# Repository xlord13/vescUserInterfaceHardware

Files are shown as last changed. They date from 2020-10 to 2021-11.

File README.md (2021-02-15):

# User interface board for VESC controller on e-twow scooter

This user interface board is based on an stm32F4 microcontroler.
The hardware design has been optimized for e-twow scooters, but can be adapted to any electric engine.
Is has been made with KiCad, which is a cross platform and open source electronics design automation suite.

This board communicates with a VESC controller by a UART interface.
It has 4 buttons and a color OLED 128x128 display (SSD1351) for user interaction.
Additionnaly, it includes 6 leds and a photo resistor for automatic lighting when ambient lighting is too low.

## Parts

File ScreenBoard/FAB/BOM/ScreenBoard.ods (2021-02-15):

Component Count: | 23
Ref | Qnty | Value | Cmp name | Footprint | Description | Vendor | Ref
C1, C4, C7, C10, | 4 | 4.7µF | C_Small | Capacitor_SMD:C_0603_1608Metric_Pad1.05x0.95mm_HandSolder | Unpolarized capacitor, small symbol | Mouser
C2, C9, | 2 | 100nF | C_Small | Capacitor_SMD:C_0603_1608Metric_Pad1.05x0.95mm_HandSolder | Unpolarized capacitor, small symbol | Farnell
C3, C11, | 2 | 10µF | C_Small | Capacitor_SMD:C_1206_3216Metric_Pad1.42x1.75mm_HandSolder | Unpolarized capacitor, small symbol | Mouser
C5, C8, | 2 | 1µF | C_Small | Capacitor_SMD:C_0805_2012Metric_Pad1.15x1.40mm_HandSolder | Unpolarized capacitor, small symbol | Mouser
C6, | 1 | 120pF | C_Small | Capacitor_SMD:C_0603_1608Metric_Pad1.05x0.95mm_HandSolder | Unpolarized capacitor, small symbol | Mouser
D1, D2, | 2 | 1N4148WT | 1N4148WT | Diode_SMD:D_SOD-523 | 75V 0.15A Fast switching Diode, SOD-523 | Mouser
D3, | 1 | MBRS130LT3G | D_Schottky_ALT | Diode_SMD:D_SMB_Handsoldering | Schottky diode, filled shape | Mouser
IC1, | 1 | FAN5331SX | FAN5331SX | SOT95P280X145-5N | ON Semiconductor FAN5331SX, LED Driver, 3.3 V, 5 V, 5-Pin SOT-23 | Mouser
J1, | 1 | Micro_SD_Card | Micro_SD_Card | SamacSys_Parts:693072010801 | Micro SD Card Socket | Mouser
J2, | 1 | Conn_02x05_Male | Conn_02x05_Odd_Even | Connector_PinHeader_2.00mm:PinHeader_2x05_P2.00mm_Vertical_SMD | Generic connector, double row, 02x05, odd/even pin numbering scheme (row 1 odd numbers, row 2 even numbers), script generated (kicad-library-utils/schlib/autogen/connector/) | Mouser
K1, | 1 | OLED connector | K_0051-DVB_K-DK3_GUI-PI-rescue | SamacSys_Parts:52435-3071 |  | Mouser
L1, | 1 | 10µH | L_Small | Inductor_SMD:L_Coilcraft_LPS5030 | Inductor, small symbol | Mouser
R1, | 1 | 56 Ohm | R_Small | Resistor_SMD:R_0603_1608Metric_Pad1.05x0.95mm_HandSolder | Resistor, small symbol | Mouser
R2, | 1 | 10k | R_Small | Resistor_SMD:R_0603_1608Metric_Pad1.05x0.95mm_HandSolder | Resistor, small symbol | Farnell
R3, | 1 | 100k | R_Small | Resistor_SMD:R_0603_1608Metric_Pad1.05x0.95mm_HandSolder | Resistor, small symbol | Mouser
R4, | 1 | 600k (604k) | R_Small | Resistor_SMD:R_0603_1608Metric_Pad1.05x0.95mm_HandSolder | Resistor, small symbol | Mouser

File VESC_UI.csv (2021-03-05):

Ref | Qnty | Value | Cmp name | Footprint | Description | Vendor
C1, | 1 | 10n | C_Small | Capacitor_SMD:C_0603_1608Metric_Pad1.05x0.95mm_HandSolder | Unpolarized capacitor, small symbol
C2, | 1 | 10µF | C | Capacitor_SMD:C_0805_2012Metric_Pad1.15x1.40mm_HandSolder | Unpolarized capacitor
C6, C9, C10, C12, C15, C19, C20, C21, C23, C24, | 10 | 100n | C_Small | Capacitor_SMD:C_0603_1608Metric_Pad1.05x0.95mm_HandSolder | Unpolarized capacitor, small symbol
C18, | 1 | 4.7u | C_Small | Capacitor_SMD:C_0603_1608Metric_Pad1.05x0.95mm_HandSolder | Unpolarized capacitor, small symbol
C22, | 1 | SUpercap 330mF | Battery_Cell | SamacSys_Parts:DSK3R3H334THL | Single-cell battery
D1, D2, D3, D4, D5, D6, | 6 | LED 5mm - White | LED_Small_ALT | LED_THT:LED_D5.0mm_Horizontal_O1.27mm_Z3.0mm_Clear | Light emitting diode, small symbol, filled shape
D10, | 1 | Schottky CD0603-B0240R | D_Schottky_Small_ALT | Diode_SMD:D_0603_1608Metric_Pad1.05x0.95mm_HandSolder | Schottky diode, small symbol, filled shape
J1, J2, | 2 | Hall_SS441R | Conn_01x03_Female | Package_TO_SOT_THT:TO-92Flat | Generic connector, single row, 01x03, script generated (kicad-library-utils/schlib/autogen/connector/)
J3, | 1 | Conn_01x07_Male | Conn_01x07_Male | Connector_JST:JST_PH_B7B-PH-K_1x07_P2.00mm_Vertical | Generic connector, single row, 01x07, script generated (kicad-library-utils/schlib/autogen/connector/)
J4, | 1 | Conn_02x05_Female | Conn_02x05_Odd_Even | Connector_PinSocket_2.00mm:PinSocket_2x05_P2.00mm_Vertical | Generic connector, double row, 02x05, odd/even pin numbering scheme (row 1 odd numbers, row 2 even numbers), script generated (kicad-library-utils/schlib/autogen/connector/)
J5, | 1 | Conn_01x05_Male | Conn_01x05_Male | Connector_JST:JST_PH_B5B-PH-K_1x05_P2.00mm_Vertical | Generic connector, single row, 01x05, script generated (kicad-library-utils/schlib/autogen/connector/)
J6, | 1 | Conn_01x04_Male | Conn_01x04_Male | Connector_JST:JST_PH_B4B-PH-K_1x04_P2.00mm_Vertical | Generic connector, single row, 01x04, script generated (kicad-library-utils/schlib/autogen/connector/)
J8, J9, | 2 | Conn_01x02_Male | Conn_01x02_Male | Connector_JST:JST_PH_B2B-PH-K_1x02_P2.00mm_Vertical | Generic connector, single row, 01x02, script generated (kicad-library-utils/schlib/autogen/connector/)
JP1, JP2, | 2 | Jumper_NC_Small | Jumper_NC_Small | Jumper:SolderJumper-2_P1.3mm_Open_TrianglePad1.0x1.5mm | Jumper, normally closed, small symbol
L2, | 1 | MMZ1608B121CTDH5 | L_Core_Iron_Small | Inductor_SMD:L_0603_1608Metric_Pad1.05x0.95mm_HandSolder | Inductor with iron core, small symbol
Q1, Q2, | 2 | Mosfet IRLML2060TRPBF | IRLML2060 | Package_TO_SOT_SMD:SOT-23 | 1.2A Id, 60V Vds, N-Channel MOSFET, 480mOhm Rds, SOT-23
R1, R4, R6, R10, R11, R15, | 6 | 62 | R_Small | Resistor_SMD:R_0603_1608Metric_Pad1.05x0.95mm_HandSolder | Resistor, small symbol
R2, | 1 | 100k | R_Small | Resistor_SMD:R_0603_1608Metric_Pad1.05x0.95mm_HandSolder | Resistor, small symbol
R3, R5, R7, R9, R12, | 5 | 100 | R_Small | Resistor_SMD:R_0603_1608Metric_Pad1.05x0.95mm_HandSolder | Resistor, small symbol
R8, | 1 | 1M | R_Small | Resistor_SMD:R_0603_1608Metric_Pad1.05x0.95mm_HandSolder | Resistor, small symbol
R13, | 1 | NSL-19M51 | R_PHOTO | OptoDevice:R_LDR_4.9x4.2mm_P2.54mm_Vertical | Photoresistor
R14, R21, R22, | 3 | 10k | R_Small | Resistor_SMD:R_0603_1608Metric_Pad1.05x0.95mm_HandSolder | Resistor, small symbol
R17, R18, | 2 | 0 | R_Small | Resistor_SMD:R_0603_1608Metric_Pad1.05x0.95mm_HandSolder | Resistor, small symbol
SW1, SW2, SW3, SW4, | 4 | Vertical push button | SW_Push | SamacSys_Parts:Vertical_push_button | Push button switch, generic, two pins
SW5, | 1 | Push button | SW_Push | Button_Switch_SMD:SW_SPST_B3U-1000P-B | Push button switch, generic, two pins
U2, | 1 | STM32F401CEU6 | STM32F401CEUx | Package_DFN_QFN:QFN-48-1EP_7x7mm_P0.5mm_EP5.6x5.6mm | ARM Cortex-M4 MCU, 512KB flash, 96KB RAM, 84MHz, 1.7-3.6V, 36 GPIO, UFQFPN-48
U3, | 1 | M95M04-DR | M95256-WMN6P | Package_SO:SOIC-8_3.9x4.9mm_P1.27mm | SPI EEPROM, 256Kb (32K x 8), No Identification Page, 2.5 to 5.5V, SO8

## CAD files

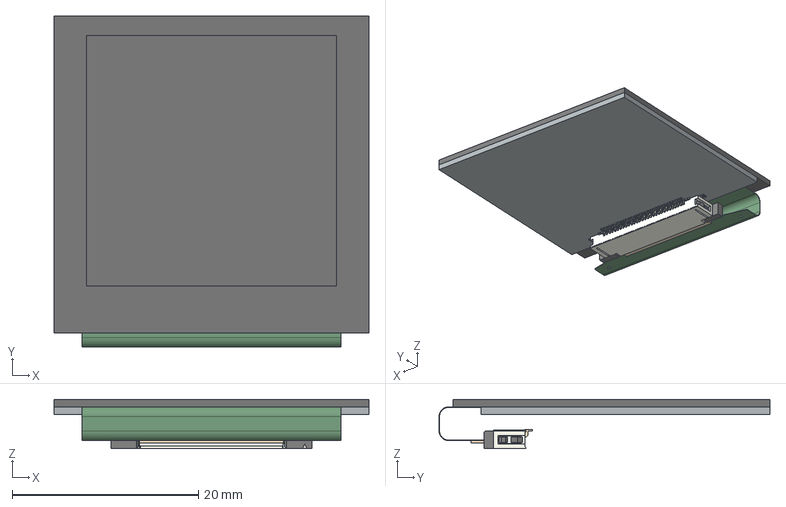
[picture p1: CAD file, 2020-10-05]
3D/SSD1351/SSD1351_Connector_v3_cp.step
33.8 x 35.5 x 5.27 mm

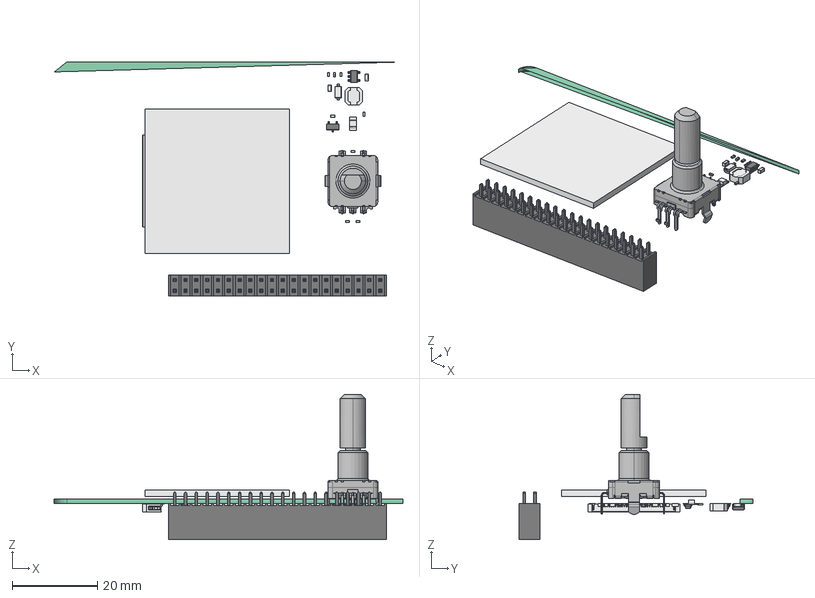
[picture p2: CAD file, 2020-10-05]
VESC_UI.FCStd
82.0 x 55.0 x 34.1 mm
Pcb_cf18
SW1_EC11E-05SW_5F084975
C8_C_0805_5CB976D5
R1_R_0402_5CB88870
D4_LED_3216-RV-red_5CBB4279
R8_R_0402_5F09672A
L1_Coilcraft-LPZ4018_5CB8885F
C1_C_0603_5CB8871C
C9_C_0603_5CB977C8
C10_C_0603_5CB976A5
D3_D_SOD-523_5CB97622
C6_C_0603_5CB97738
Q1_SOT_23_5CC6B4F7
K1_52435-3071_5CB9753E
K1__24353071_cp_sp_5CB9753E[2]
R3_R_0402_5CB975EB
C13_C_0402_5D56A2AD
U1_SOT_23_5_5CB888B8
C5_C_1206_5CB97768
C4_C_0603_5CB8874F
R10_R_0402_5CD18970
R9_R_0402_5CC6B508
R2_R_0402_5CB88881
R6_R_0402_5D5FDE48
C3_C_0603_5CB97798
C14_C_0402_5D56A2BE
D2_D_SOD-523_5CB97667
C7_C_0805_5CB97708
C2_C_0402_5CB8872D
R11_R_0402_5D56A2E0
R4_R_0402_5CBA7511
D1_D_SOD-123_5CB887CE
C15_C_0402_5D56A2CF
K6__SSQ-120-01-G-D_terminal_sp_5CADED16

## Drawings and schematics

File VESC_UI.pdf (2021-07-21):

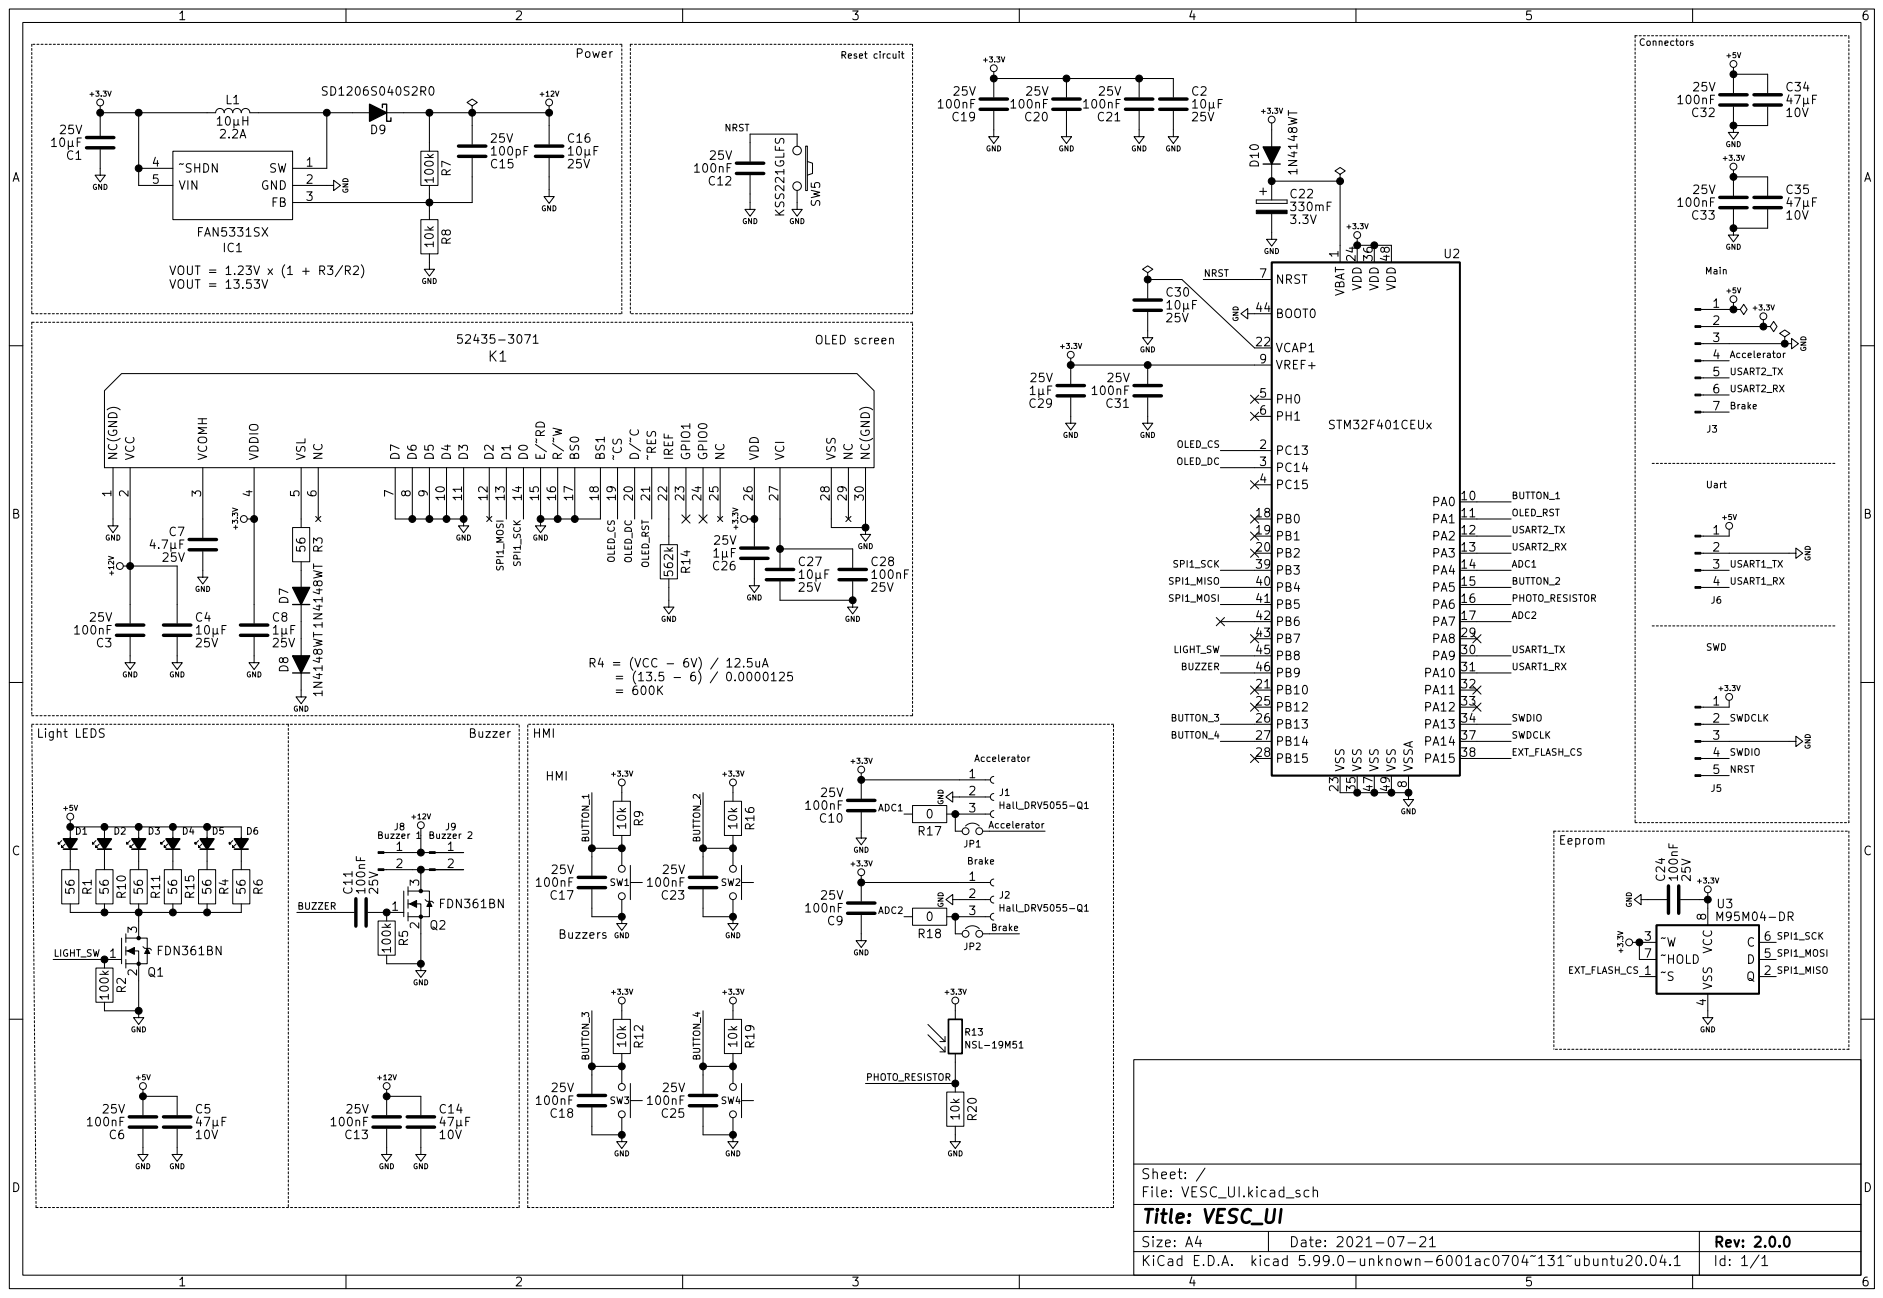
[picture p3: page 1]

1 PA0 10 PA1 11 PA2 12 PA3 13 PA4 14 PA5 15 PA6 16 PA7 17 PB0 18 PB1 19 PC13 2 PB2 20 PB10 21 VCAP1 22 VSS 23 VDD 24 PB12 25 PB13 26 PB14 27 PB15 28 PA8 29 PC14 3 PA9 30 PA10 31 PA11 32 PA12 33 PA13 34 VSS 35 VDD 36 PA14 37 PA15 38 PB3 39 PC15 4 PB4 40 PB5 41 PB6 42 PB7 43 BOOT0 44 PB8 45 PB9 46 VSS 47 VDD 48 VSS 49 PH0 5 PH1 6 NRST 7 VSSA

2 D/~C 20 ~RES 21 IREF 22 GPIO1 23 GPIO0 24 NC 25 VDD 26 VCI 27 VSS 28 NC 29 VCOMH

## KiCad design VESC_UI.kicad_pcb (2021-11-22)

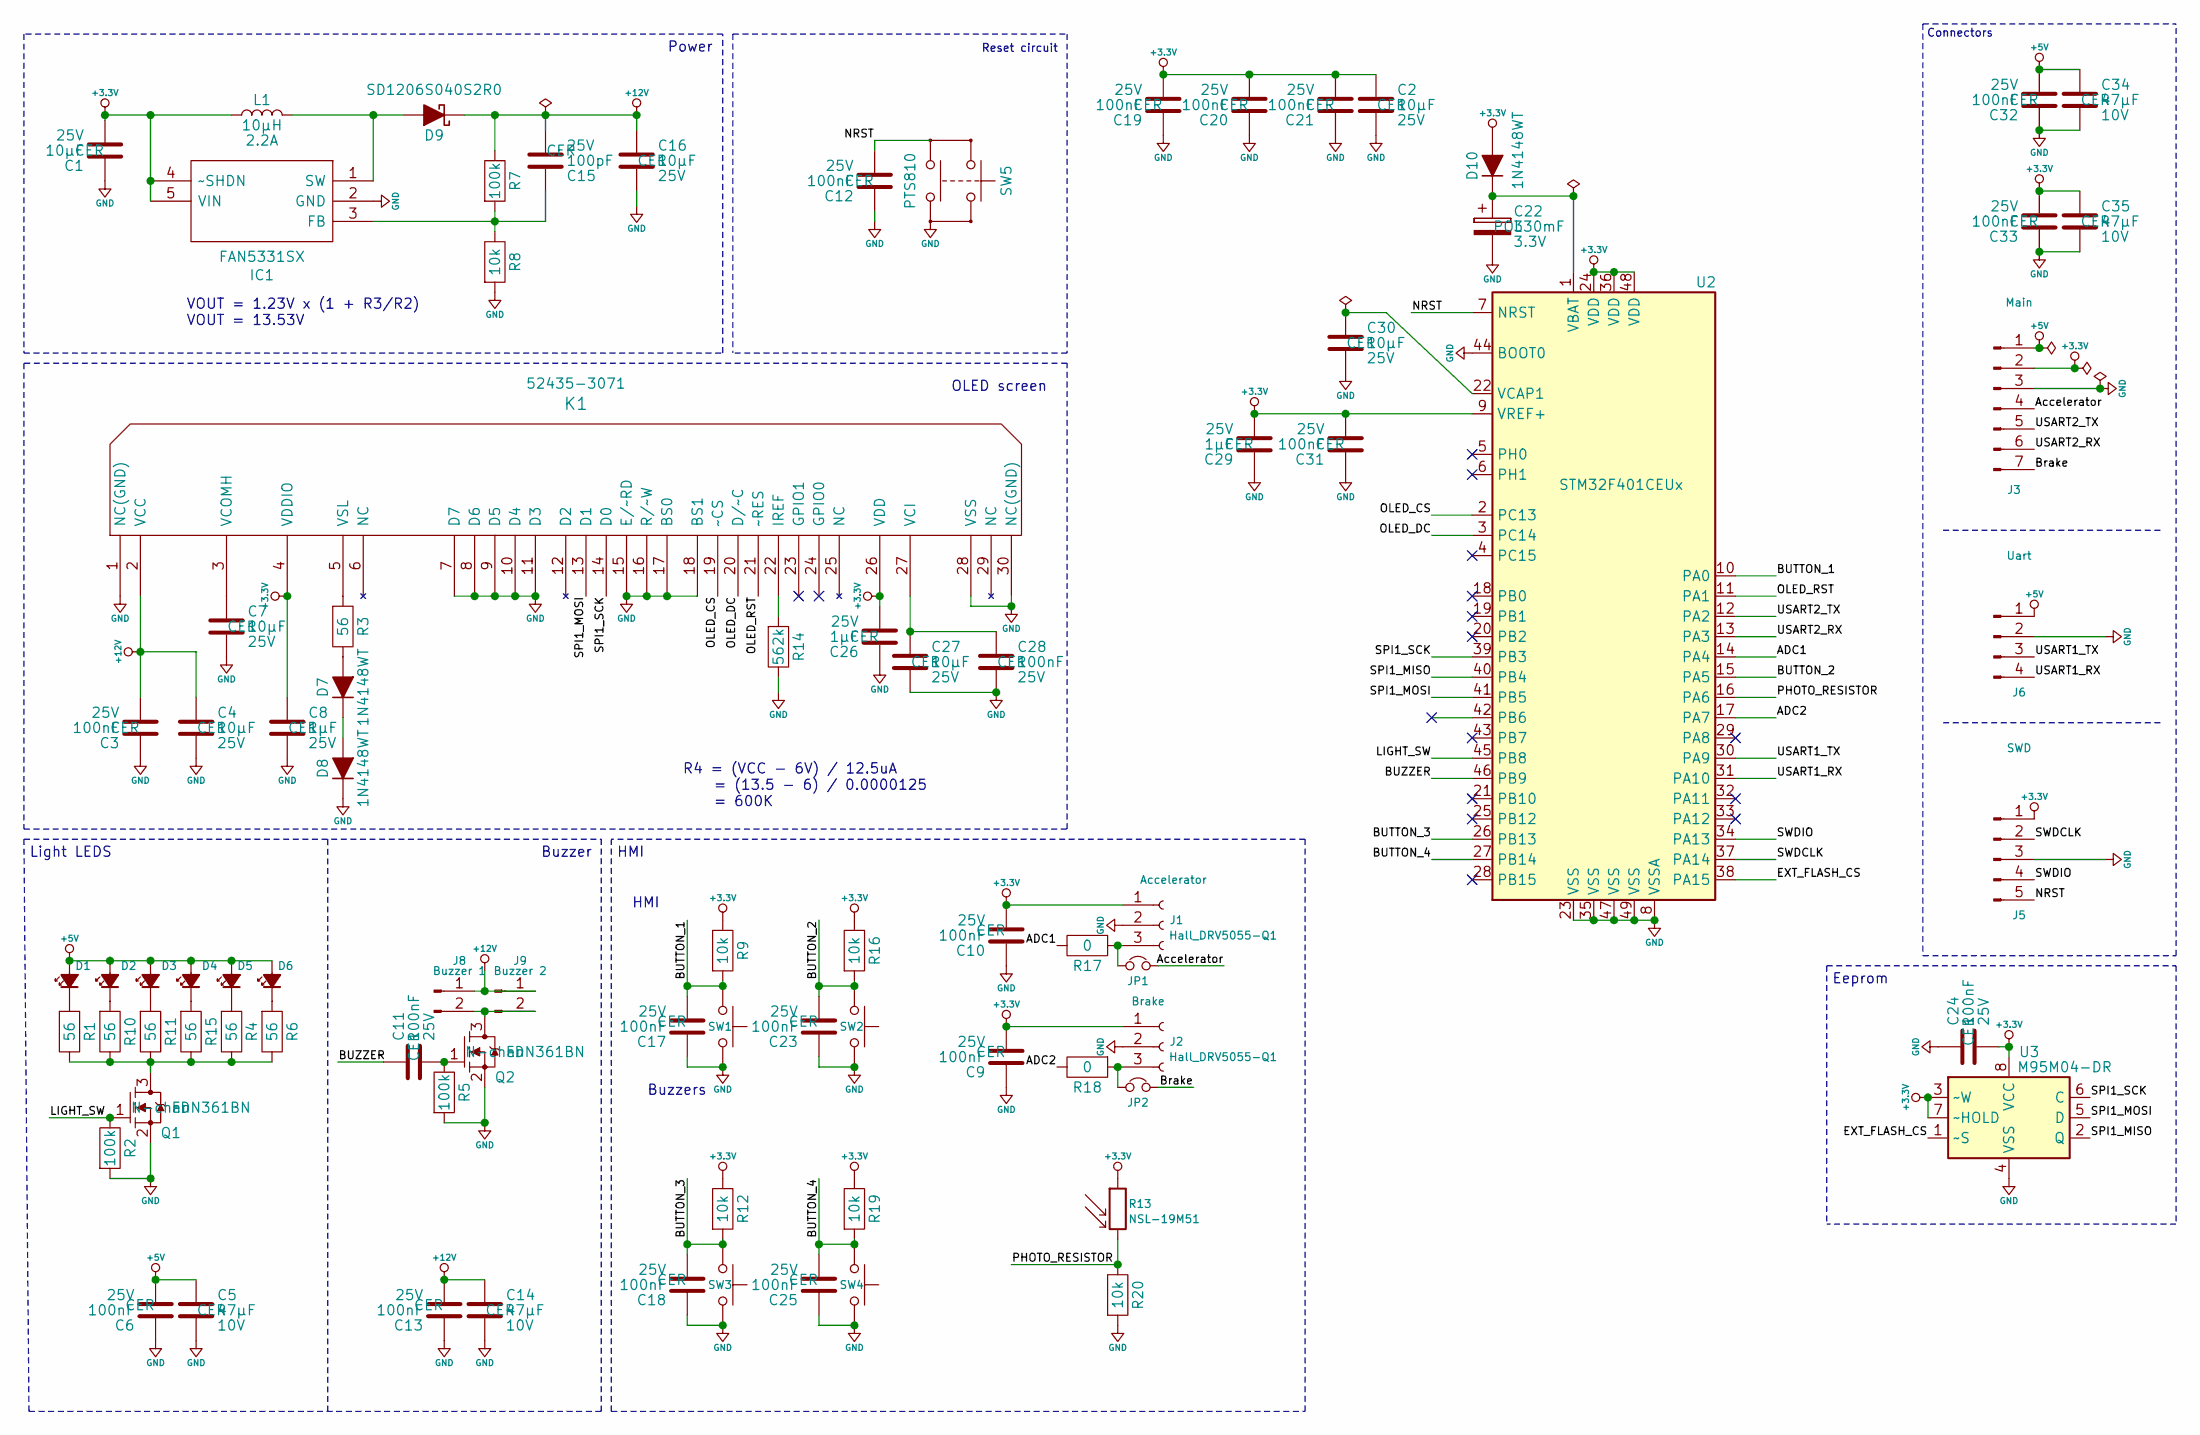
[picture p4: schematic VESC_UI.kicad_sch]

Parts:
C1, C2, C4, C7, C16, C27, C30: C_0003; C_0603
C3, C6, C9, C10, C11, C12, C13, C17, C18, C19, C20, C21, C23, C24, C25, C28, C31, C32, C33: C_0002; C_0402
C5, C14, C34, C35: C_0040; C_1210
C8, C26, C29: C_0037; C_0603
C15: C_0051; C_0402
C22: C_0046; CP_ELNA-DSK621
D1, D2, D3, D4, D5, D6: LED 5mm - White; LED_D5.0mm_Horizontal_O1.27mm_Z3.0mm_Clear
D7, D8, D10: D_0022; D_SOD-523-F
D9: D_0016; D_SOD-123
IC1: FAN5331SX; SOT95P280X145-5N; Mouser Part Number 512-FAN5331SX
J1, J2: Hall_DRV5055-Q1; TO-92Flat
J3: Conn_01x07_Male; JST_PH_B7B-PH-K_1x07_P2.00mm_Vertical
J5: Conn_01x05_Male; JST_PH_B5B-PH-K_1x05_P2.00mm_Vertical
J6: Conn_01x04_Male; JST_PH_B4B-PH-K_1x04_P2.00mm_Vertical
J8, J9: Conn_01x02_Male; JST_PH_B2B-PH-K_1x02_P2.00mm_Vertical
JP1, JP2: Jumper_NC_Small; SolderJumper-2_P1.3mm_Open_TrianglePad1.0x1.5mm
K1: K_0051-OBSOLETE; OLED128x128-1P5
L1: L_0006; L_4012-Wurth
Q1, Q2: Q_0020; SOT_23
R1, R4, R6, R10, R11, R15: R_0110; R_0603
R2, R5, R7: R_0034; R_0402
R3: R_0110; R_0402
R8, R9, R12, R16, R19, R20: R_0020; R_0402
R13: NSL-19M51; R_LDR_4.9x4.2mm_P2.54mm_Vertical
R14: R_0019; R_0402
R17, R18: R_0001; R_0402
SW1, SW2, SW3, SW4: Vertical push button; Vertical_push_button
SW5: SW_0003; PTS810
U2: STM32F401CEUx; QFN-48-1EP_7x7mm_P0.5mm_EP5.6x5.6mm
U3: M95M04-DR; SOIC-8_3.9x4.9mm_P1.27mm

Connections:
+3.3V: C1.2, C2.1, C8.1, C9.2, C10.2, C19.2, C20.2, C21.2, C24.2, C26.2, C29.2, C31.2, C33.2, C35.1, D10.2 (A), IC1.4 (~SHDN), IC1.5 (VIN), J1.1, J2.1, J3.2, J5.1, K1.4 (VDDIO), K1.26 (VDD), L1.2, R9.2, R12.2, R13.1, R16.2, R19.2, U2.9 (VREF+), U2.24 (VDD), U2.36 (VDD), U2.48 (VDD), U3.3 (~W), U3.7 (~HOLD), U3.8 (VCC)
+5V: C5.1, C6.2, C32.2, C34.1, D1.2 (A), D2.2 (A), D3.2 (A), D4.2 (A), D5.2 (A), D6.2 (A), J3.1, J6.1
+12V: C3.2, C4.1, C13.2, C14.1, C15.2, C16.1, D9.1 (K), J8.1, J9.1, K1.2 (VCC), R7.2
/ADC1: R17.2, U2.14 (PA4)
/ADC2: R18.2, U2.17 (PA7)
/Accelerator: J3.4, JP1.2
/BUTTON_1: C17.2, R9.1, SW1.1, U2.10 (PA0)
/BUTTON_2: C23.2, R16.1, SW2.1, U2.15 (PA5)
/BUTTON_3: C18.2, R12.1, SW3.1, U2.26 (PB13)
/BUTTON_4: C25.2, R19.1, SW4.1, U2.27 (PB14)
/BUZZER: C11.1, U2.46 (PB9)
/Brake: J3.7, JP2.2
/EXT_FLASH_CS: U2.38 (PA15), U3.1 (~S)
/LIGHT_SW: Q1.1 (G), R2.2, U2.45 (PB8)
/NRST: C12.2, J5.5, SW5.2, U2.7 (NRST)
/OLED_CS: K1.19 (~CS), U2.2 (PC13)
/OLED_DC: K1.20 (D/~C), U2.3 (PC14)
/OLED_RST: K1.21 (~RES), U2.11 (PA1)
/PHOTO_RESISTOR: R13.2, R20.2, U2.16 (PA6)
/SPI1_MISO: U2.40 (PB4), U3.2 (Q)
/SPI1_MOSI: K1.13 (D1), U2.41 (PB5), U3.5 (D)
/SPI1_SCK: K1.14 (D0), U2.39 (PB3), U3.6 (C)
/SWDCLK: J5.2, U2.37 (PA14)
/SWDIO: J5.4, U2.34 (PA13)
/USART1_RX: J6.4, U2.31 (PA10)
/USART1_TX: J6.3, U2.30 (PA9)
/USART2_RX: J3.6, U2.13 (PA3)
/USART2_TX: J3.5, U2.12 (PA2)
GND: C1.1, C2.2, C3.1, C4.2, C5.2, C6.1, C7.2, C8.2, C9.1, C10.1, C12.1, C13.1, C14.2, C16.2, C17.1, C18.1, C19.1, C20.1, C21.1, C22.2, C23.1, C24.1, C25.1, C26.1, C27.2, C28.2, C29.1, C30.2, C31.1, C32.1, C33.1, C34.2, C35.2, D8.1 (K), IC1.2 (GND), J1.2, J2.2, J3.3, J5.3, J6.2, K1.1 (NC(GND)), K1.7 (D7), K1.8 (D6), K1.9 (D5), K1.10 (D4), K1.11 (D3), K1.15 (E/~RD), K1.16 (R/~W), K1.17 (BS0), K1.18 (BS1), K1.28 (VSS), K1.30 (NC(GND)), Q1.2 (S), Q2.2 (S), R2.1, R5.1, R8.1, R14.2, R20.1, SW1.2, SW2.2, SW3.2, SW4.2, SW5.3, U2.8 (VSSA), U2.23 (VSS), U2.35 (VSS), U2.44 (BOOT0), U2.47 (VSS), U2.49 (VSS), U3.4 (VSS)
unnamed: C7.1, K1.3 (VCOMH)
unnamed: C11.2, Q2.1 (G), R5.2
unnamed: C15.1, IC1.3 (FB), R7.1, R8.2
unnamed: C22.1, D10.1 (K), U2.1 (VBAT)
unnamed: C27.1, C28.1, K1.27 (VCI)
unnamed: C30.1, U2.22 (VCAP1)
unnamed: D1.1 (K), R1.1
unnamed: D2.1 (K), R10.1
unnamed: D3.1 (K), R11.1
unnamed: D4.1 (K), R15.1
unnamed: D5.1 (K), R4.1
unnamed: D6.1 (K), R6.1
unnamed: D7.1 (K), D8.2 (A)
unnamed: D7.2 (A), R3.2
unnamed: D9.2 (A), IC1.1 (SW), L1.1
unnamed: J1.3, JP1.1, R17.1
unnamed: J2.3, JP2.1, R18.1
unnamed: J8.2, J9.2, Q2.3 (D)
unnamed: K1.5 (VSL), R3.1
unnamed: K1.22 (IREF), R14.1
unnamed: Q1.3 (D), R1.2, R4.2, R6.2, R10.2, R11.2, R15.2

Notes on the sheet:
Buzzer
HMI
Eeprom
Buzzers
Light LEDS
R4 = (VCC - 6V) / 12.5uA = (13.5 - 6) / 0.0000125 = 600K
Power
Connectors
Reset circuit
OLED screen
VOUT = 1.23V x (1 + R3/R2) VOUT = 13.53V

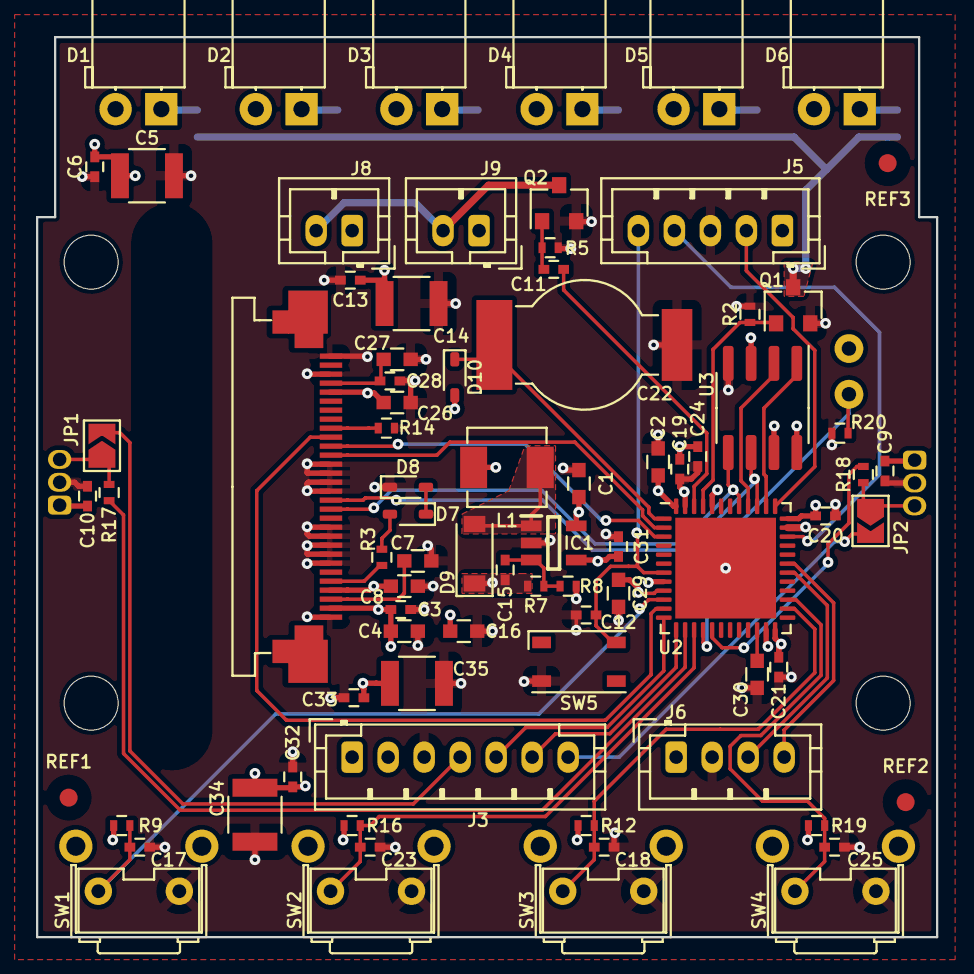
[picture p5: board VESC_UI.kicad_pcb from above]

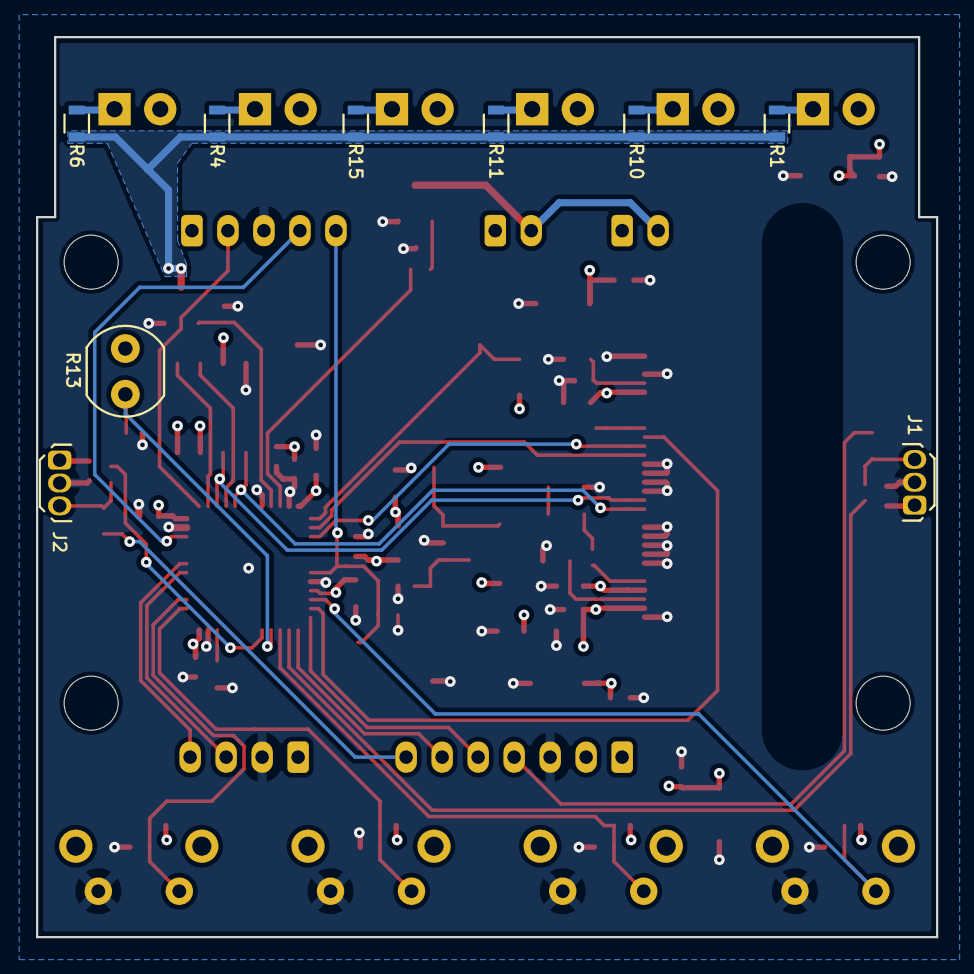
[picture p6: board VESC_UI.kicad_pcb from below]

Board: 4 copper layers, 50.0 x 50.0 mm, 93 parts (9 on the bottom side), 50 nets.

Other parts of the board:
Hole1, Hole2, Hole3, Hole4: MountingHole_3.2mm_M3_DIN965
REF1, REF2, REF3: CircleWhite1mm; REF_1mm

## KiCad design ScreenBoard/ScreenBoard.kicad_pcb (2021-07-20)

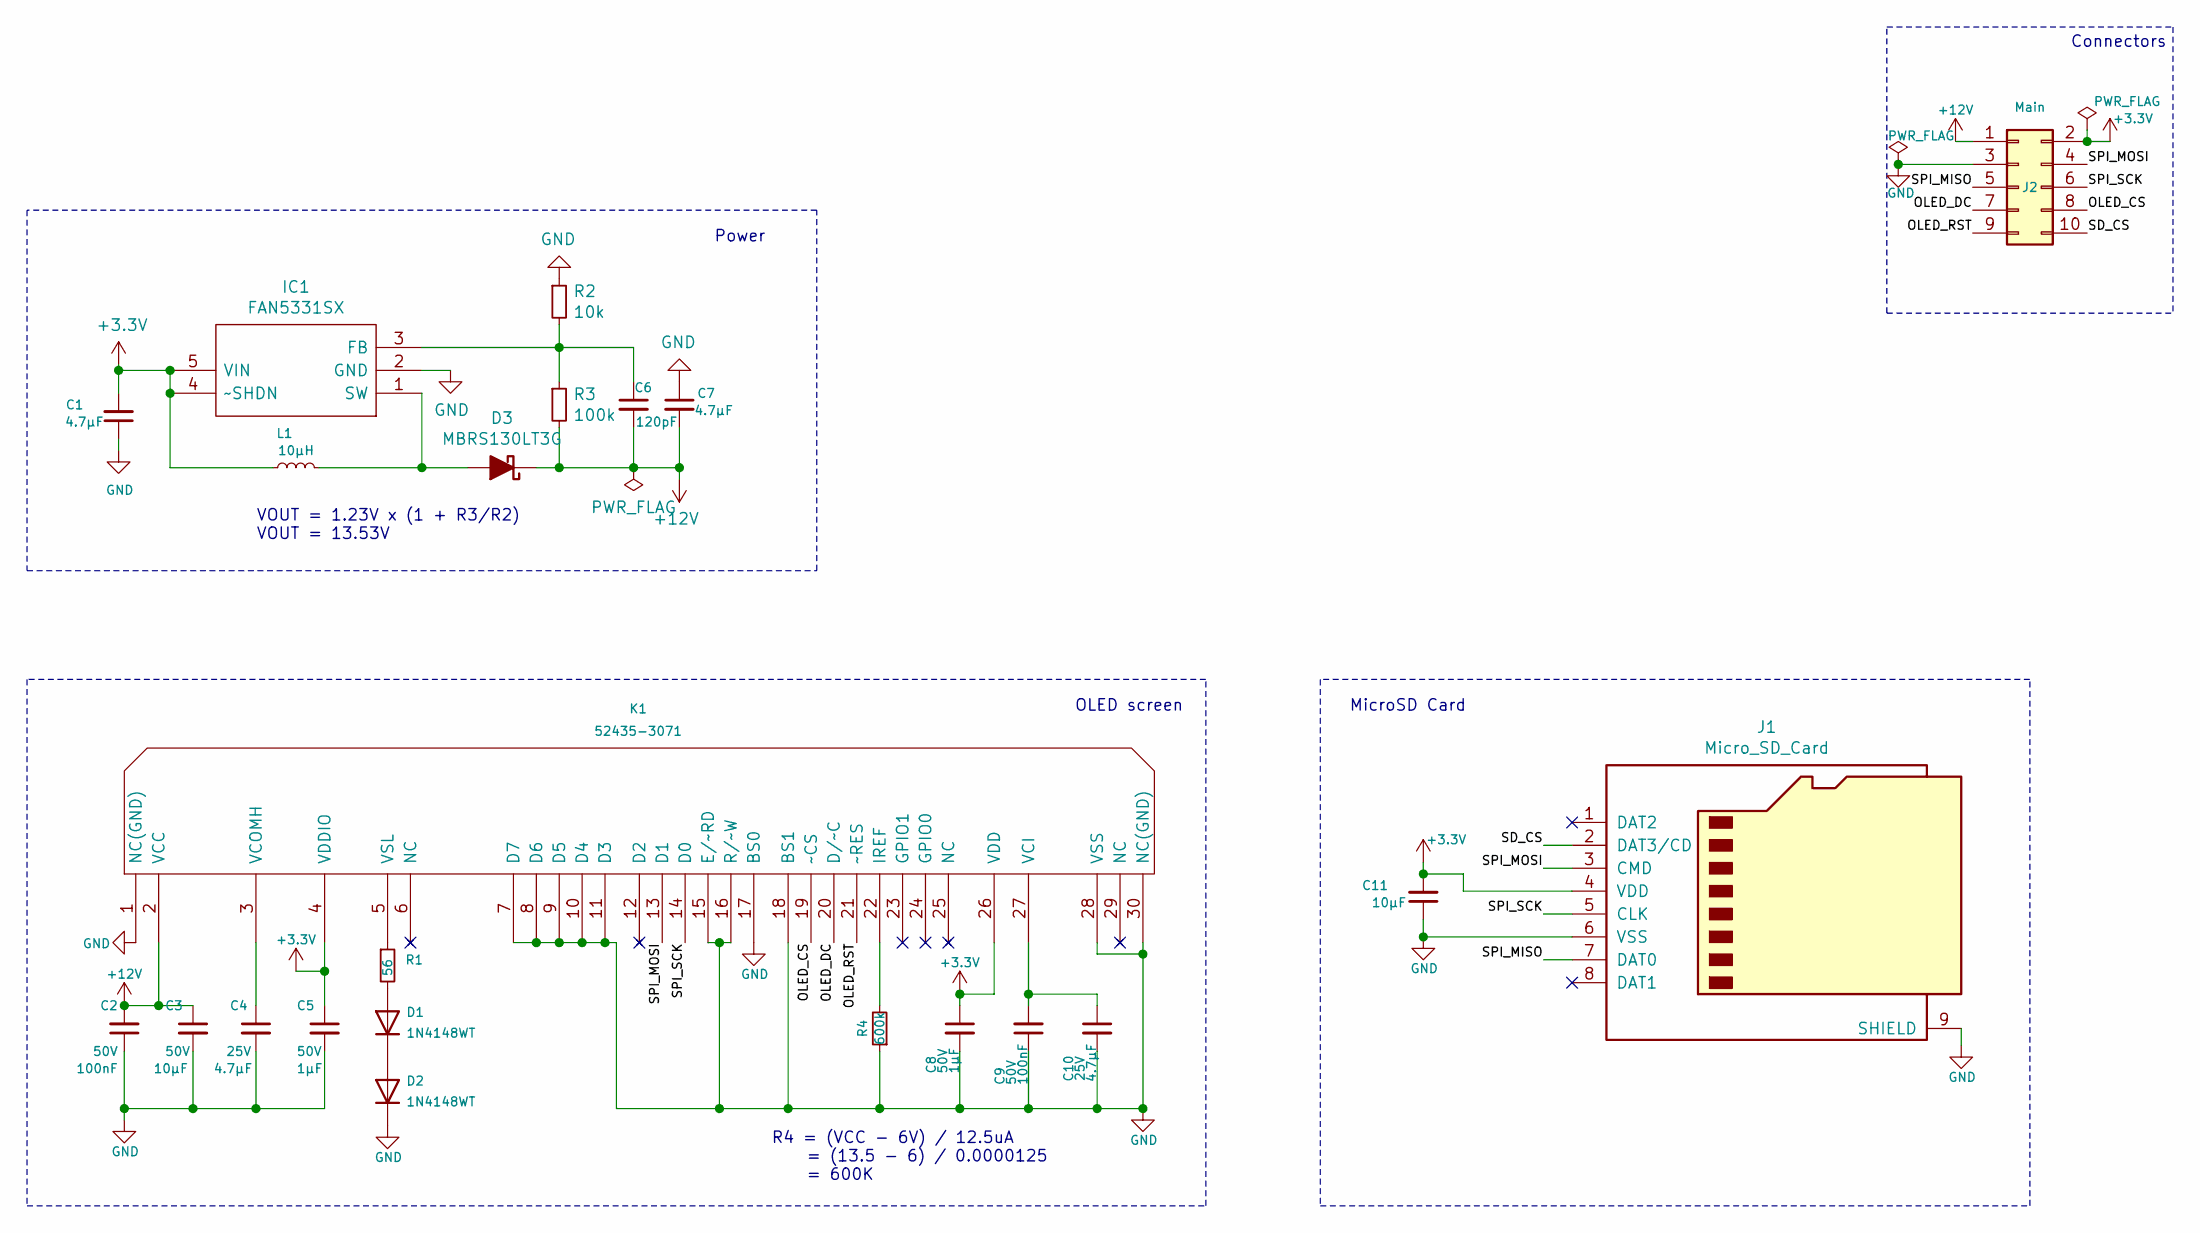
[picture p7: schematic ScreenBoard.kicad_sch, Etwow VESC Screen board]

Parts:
C1, C4, C7, C10: 4.7µF; C_0603_1608Metric_Pad1.05x0.95mm_HandSolder
C2, C9: 100nF; C_0603_1608Metric_Pad1.05x0.95mm_HandSolder
C3, C11: 10µF; C_1206_3216Metric_Pad1.42x1.75mm_HandSolder
C5, C8: 1µF; C_0805_2012Metric_Pad1.15x1.40mm_HandSolder
C6: 120pF; C_0603_1608Metric_Pad1.05x0.95mm_HandSolder
D1, D2: 1N4148WT; D_SOD-523
D3: MBRS130LT3G; D_SMB_Handsoldering
IC1: FAN5331SX; SOT95P280X145-5N; Mouser Part Number 512-FAN5331SX
J1: Micro_SD_Card; 693072010801
J2: Conn_02x05_Male; PinHeader_2x05_P2.00mm_Vertical_SMD
K1: OLED connector; 52435-3071
L1: 10µH; L_Coilcraft_LPS5030
R1: 56 Ohm; R_0603_1608Metric_Pad1.05x0.95mm_HandSolder
R2: 10k; R_0603_1608Metric_Pad1.05x0.95mm_HandSolder
R3: 100k; R_0603_1608Metric_Pad1.05x0.95mm_HandSolder
R4: 600k; R_0603_1608Metric_Pad1.05x0.95mm_HandSolder

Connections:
+3V3: C1.2, C5.1, C8.1, C11.2, IC1.4 (~SHDN), IC1.5 (VIN), J1.4 (VDD), J2.2, K1.4 (VDDIO), K1.26 (VDD), L1.1
+12V: C2.2, C3.1, C6.2, C7.2, D3.1 (K), J2.1, K1.2 (VCC), R3.2
/OLED_CS: J2.8, K1.19 (~CS)
/OLED_DC: J2.7, K1.20 (D/~C)
/OLED_RST: J2.9, K1.21 (~RES)
/SD_CS: J1.2 (DAT3/CD), J2.10
/SPI_MISO: J1.7 (DAT0), J2.5
/SPI_MOSI: J1.3 (CMD), J2.4, K1.13 (D1)
/SPI_SCK: J1.5 (CLK), J2.6, K1.14 (D0)
GND: C1.1, C2.1, C3.2, C4.2, C5.2, C7.1, C8.2, C9.1, C10.2, C11.1, D2.1 (K), IC1.2 (GND), J1.6 (VSS), J1.9 (SHIELD), J2.3, K1.1 (NC(GND)), K1.7 (D7), K1.8 (D6), K1.9 (D5), K1.10 (D4), K1.11 (D3), K1.15 (E/~RD), K1.16 (R/~W), K1.17 (BS0), K1.18 (BS1), K1.28 (VSS), K1.30 (NC(GND)), R2.1, R4.1
unnamed: C4.1, K1.3 (VCOMH)
unnamed: C6.1, IC1.3 (FB), R2.2, R3.1
unnamed: C9.2, C10.1, K1.27 (VCI)
unnamed: D1.1 (K), D2.2 (A)
unnamed: D1.2 (A), R1.2
unnamed: D3.2 (A), IC1.1 (SW), L1.2
unnamed: K1.5 (VSL), R1.1
unnamed: K1.22 (IREF), R4.2

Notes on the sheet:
VOUT = 1.23V x (1 + R3/R2) VOUT = 13.53V
Power
R4 = (VCC - 6V) / 12.5uA = (13.5 - 6) / 0.0000125 = 600K
OLED screen
MicroSD Card
Connectors

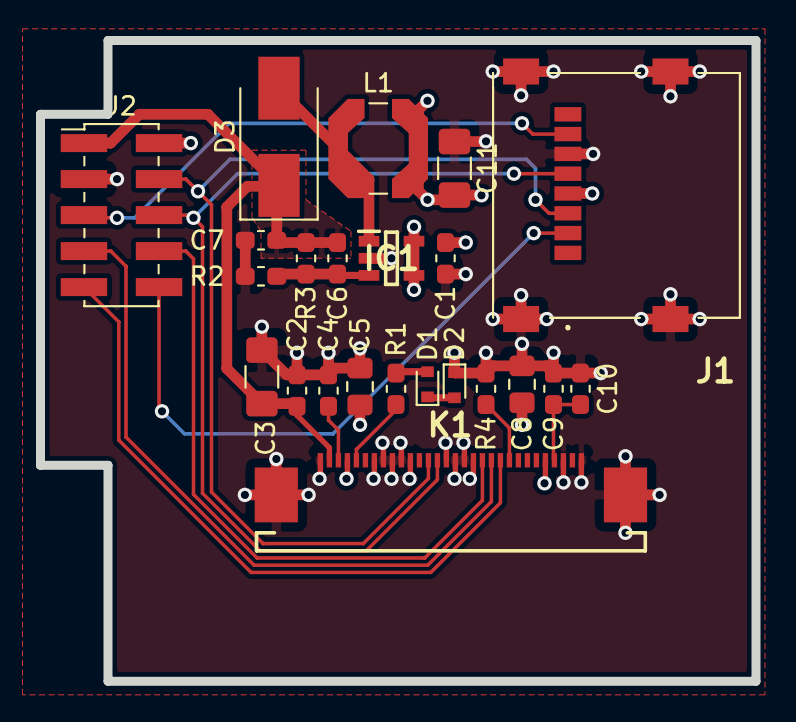
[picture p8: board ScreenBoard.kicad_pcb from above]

Board: 4 copper layers, 39.8 x 35.6 mm, 23 parts (0 on the bottom side), 18 nets.

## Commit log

2020-10-05 Add KiCad project
    [DG3-MTR_GUI-PI-B_Cu.gbl, DG3-MTR_GUI-PI-B_Mask.gbs, DG3-MTR_GUI-PI-B_Paste.gbp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]
2020-10-06 Modify crystal type
    [VESC_UI.sch]
2020-10-21 Add RTC and buzzers
    [VESC_UI.sch]
2020-12-12 first finished version
    [DG3-MTR_GUI-PI-B_Cu.gbl, DG3-MTR_GUI-PI-B_Mask.gbs, DG3-MTR_GUI-PI-B_Paste.gbp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]
2020-12-12 fix: adjust LED 3d models
    [VESC_UI.kicad_pcb]
2020-12-12 Modify some areas
    [ScreenBoard.kicad_pcb, VESC_UI.kicad_pcb, VESC_UI.xml]
2020-12-14 fix: add missing rules and components
    [ScreenBoard.kicad_pcb, VESC_UI.kicad_pcb, VESC_UI.sch]
2020-12-17 fix: change screen connector footprint and adjust its mechanical position
    [ScreenBoard.kicad_pcb, ScreenBoard.sch, VESC_UI.kicad_pcb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]
2020-12-20 adjust vias drill dimension to comply PCB provider rules
    [ScreenBoard.kicad_pcb, VESC_UI.kicad_pcb]
2020-12-21 fix and refactor: both mainboard and screenboard
    Many improvements made
    - Fixed all issues with footprints
    - Optimized components placement and tracks
    [ScreenBoard.kicad_pcb, ScreenBoard.sch, VESC_UI.kicad_pcb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]
2020-12-24 Finalize new board
    - Remove some useless components
    - Change some footprints according to components availability
    - Optimize tracks and placements
    - Fix bad LDR and screen location
    [VESC_UI.kicad_pcb, VESC_UI.sch, VESC_UI.xml]
2020-12-25 feature: change power circuit
    [ScreenBoard.sch]
2020-12-27 Finalized PCBs
    - Add MicroSD Card support on screen board
    - Fix Hall sensors footprints (flip board side)
    - Change screen connector
    [ScreenBoard.dsn, ScreenBoard.kicad_pcb, ScreenBoard.sch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]
2020-12-27 Add gerber fliles for production
    [ScreenBoard-B_CrtYd.gbr, ScreenBoard-B_Cu.gbr, ScreenBoard-B_Mask.gbr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]
2020-12-27 fix(screenBoard)
    - Wrong placement of some references on silkscreen layer
    - slightly adjust a track for homogeneity
    [ScreenBoard.kicad_pcb]
2020-12-27 Change C11 footprint for better component availability
    [ScreenBoard.kicad_pcb, ScreenBoard.sch]
2021-02-15 feature(screenBoard): add BOM and fix type on readme file
    [ScreenBoard.ods]
2021-03-05 fix(Mainboard): LEDs not working due to insufficient current
    [VESC_UI.csv, VESC_UI.kicad_pcb, VESC_UI.sch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]
2021-07-20 Update to Kicad 6
    [ScreenBoard.kicad_sch, VESC_UI.kicad_sch]
2021-07-21 Update STM32 lib
    [VESC_UI.kicad_sch]
2021-07-21 Generate PDF
    [VESC_UI.kicad_sch]
2021-08-06 Route complete
    [VESC_UI.dsn, VESC_UI.kicad_pcb, VESC_UI.kicad_sch]
2021-09-07 v2.0.0 version
    [VESC_UI-B_Cu.gbr, VESC_UI-B_Mask.gbr, VESC_UI-B_Paste.gbr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]
2021-10-13 Update pos files
    [VESC_UI.kicad_pcb]
2021-11-22 Update project for placer
    [VESC_UI.kicad_pcb, VESC_UI.kicad_sch]
